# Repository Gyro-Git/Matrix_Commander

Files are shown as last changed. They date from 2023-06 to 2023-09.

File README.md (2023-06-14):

# Matrix Commander

Matrix Commander is an open-source project dedicated to developing a customizable, 3D-printed wireless remote. This project is built around the Arduino line of microcontrollers.
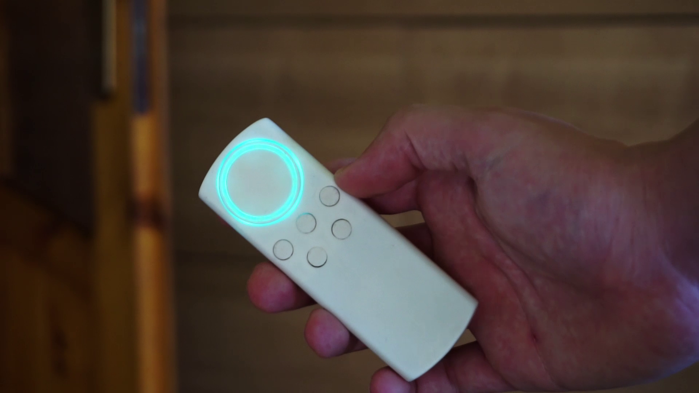
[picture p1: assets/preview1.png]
Matrix Commander

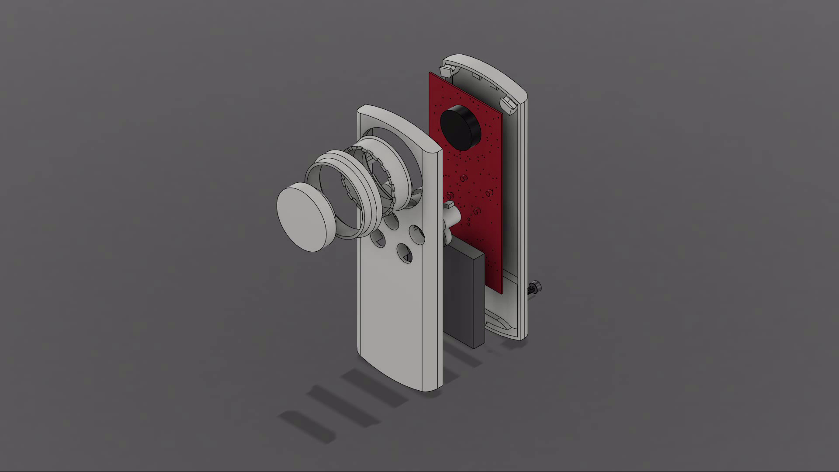
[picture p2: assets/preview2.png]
Matrix Commander render


## About

This project brings together several facets of technology, integrating hardware programming, 3D printing, and wireless connectivity. The end result is a functional human interface device(HID) that can serve as a keyboard or any other HID, making it compatible with any device that supports a regular keyboard.

For detailed instructions on the construction and implementation of Matrix Commander, refer to our comprehensive guide:

**[The Ultimate Wireless Keyboard Mark 2](https://www.instructables.com/The-Ultimate-Wireless-Keyboard-Mark-2/)**

## Key Features

- Arduino programming - providing flexibility for customization
- 3D printed design - allowing personalization
- Functions as a human interface device

## Contributing

Contributions are welcome and appreciated. Feel free to fork the project, make modifications, and submit a Pull Request.

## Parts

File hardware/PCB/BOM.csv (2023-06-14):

Qty | Value | Device | Package | Parts | Description
1 |  | USB_C16PIN | USB-C-16P | J1 | USB Type C 16Pin Connector
1 | 0.4R | R-EU_R0805 | R0805 | R17 | RESISTOR, European symbol
2 | 100nF | C-EUC0603 | C0603 | C3, C6 | CAPACITOR, European symbol
9 | 10K | R-EU_R0603 | R0603 | R3, R5, R7, R8, R9, R10, R11, R12, R27 | RESISTOR, European symbol
2 | 10k | R-EU_R0603 | R0603 | R14, R23 | RESISTOR, European symbol
2 | 10uF | C-EUC0805 | C0805 | C1, C2 | CAPACITOR, European symbol
4 | 10R | R-EU_R0603 | R0603 | R2, R4, R6, R26 | RESISTOR, European symbol
1 | 16Mhz | XTAL-4-3225 | NX3225 | Q2 | Classic 4-pin 3.2 x 2.5mm crystal
4 | 1k | R-EU_R0603 | R0603 | R16, R18, R19, R20 | RESISTOR, European symbol
2 | 1nF | C-EUC0603 | C0603 | C13, C14 | CAPACITOR, European symbol
6 | 1uF | C-EUC0603 | C0603 | C4, C5, C7, C10, C11, C12 | CAPACITOR, European symbol
2 | 22R | R-EU_R0603 | R0603 | R24, R25 | RESISTOR, European symbol
2 | 22pf | C-EUC0603 | C0603 | C8, C9 | CAPACITOR, European symbol
2 | 22R | R-EU_R0603 | R0603 | R29, R30 | RESISTOR, European symbol
1 | 2k7 | R-EU_R0603 | R0603 | R1 | RESISTOR, European symbol
1 | 32U4 | ATMEGA32U4TQFP-44 | TQFP44 | U2 | Atmel MCU, 32KByte
1 | 39R | R-EU_R0603 | R0603 | R28 | RESISTOR, European symbol
2 | 5K1 | R-EU_R0603 | R0603 | R21, R22 | RESISTOR, European symbol
2 | 5M | R-EU_R0603 | R0603 | R13, R15 | RESISTOR, European symbol
2 | AP7313 | AP7313_LINEAR_PWR_REG | SOT23R | IC2, IC3 | 3.3V Voltage Reference 50ppm/°C, SOT23, 3-Terminal
1 | ATMEGA328P_TQFP | ATMEGA328P_TQFP | TQFP32-08 | U1 | Popular 328P in QFP
1 | JST | JST_PH2.0_BAT_CON | JST_PH_2.0_2PIN_CONNECTOR | CON1
8 | LL4148 | DSOD323 | SOD323 | D1, D2, D3, D4, D5, D6, D7, D8 | DIODE
2 | NRF24 | NRF24 | NRF24L01_SMT | U$1, U$9 | SMD version of NRF24L01 wireless transceiver module. Made by Gyro: https://www.youtube.com/c/gyro1
4 | NX7002AK | MOSFET-NREFLOW | SOT23 | Q1, Q3, Q4, Q5 | N-Channel Mosfet
2 | OSHW-LOGOS | OSHW-LOGOS | OSHW-LOGO-S | LOGO1, LOGO2 | Open-Source Hardware (OSHW) Logo
6 | RGB_LED | RGB_LED | 1.6X1.6_RGB_LED | LED1, LED3, LED5, LED7, LED9, LED13
1 | SIQ-ROTARY_ENCODER | SIQ-ROTARY_ENCODER | SIQ-02FVS3 | SW1
5 | TAC_SWITCHSMD | TAC_SWITCHSMD | TACTILE-SWITCH-SMD | S1, S2, S3, S4, S5 | Momentary Switch
1 | TP4056 | TP4056 | SOP-8 | IC1
1 | USB-A | USB-A | USB-A-SMT-MALE | U$8

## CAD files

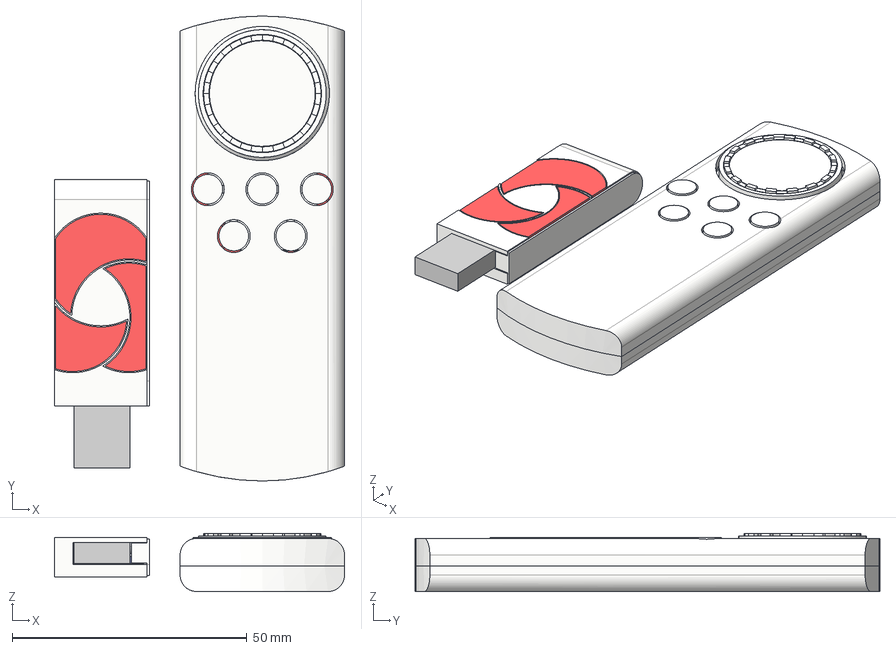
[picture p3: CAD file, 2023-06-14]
hardware/3D_models/Matrix_Commander.step
61.7 x 99.0 x 12.3 mm
NRF24
ATMEGA328P_TQFP
TP4056
TAC_SWITCHSMD x 5
RGB_LED x 11
22R x 21
NX7002AK x 3
AP7313
LL4148 x 8
OSHW-LOGOS
10uF x 2
0.4R
1uF x 3
PAD_POGO_PIN x 8
Skrutka
zavit
Buttons
Bottom
Top
li-po 500mah
mid
out
ring
receiver

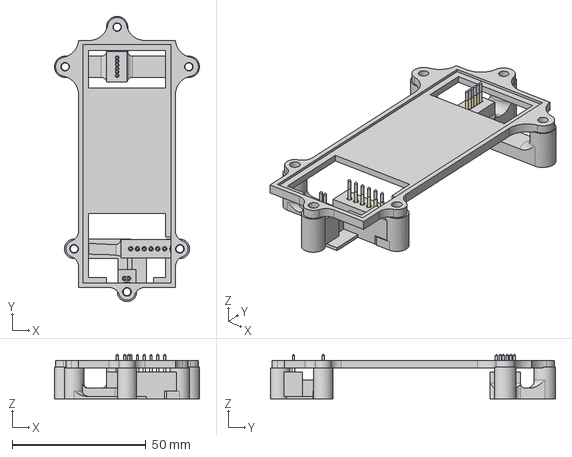
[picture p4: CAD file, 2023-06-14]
hardware/3D_models/programing_jig.step
54.3 x 106.8 x 16.8 mm
Head x 14

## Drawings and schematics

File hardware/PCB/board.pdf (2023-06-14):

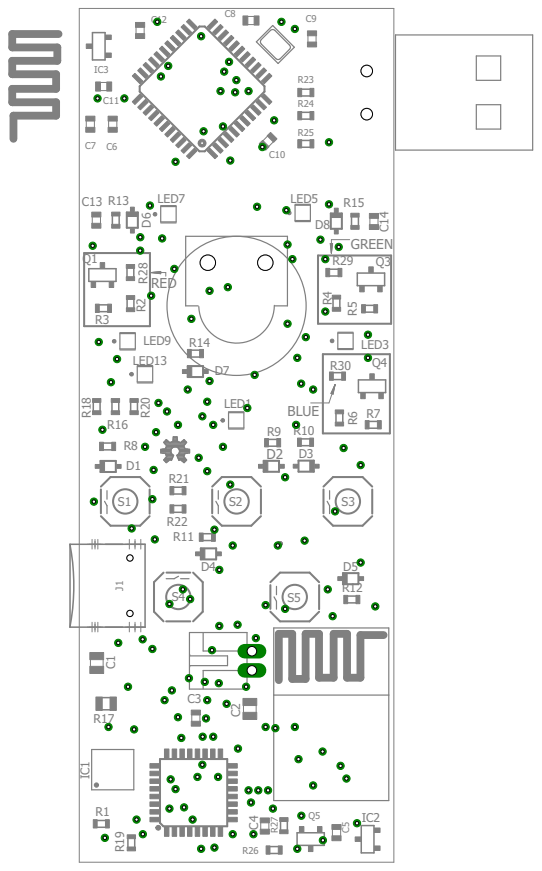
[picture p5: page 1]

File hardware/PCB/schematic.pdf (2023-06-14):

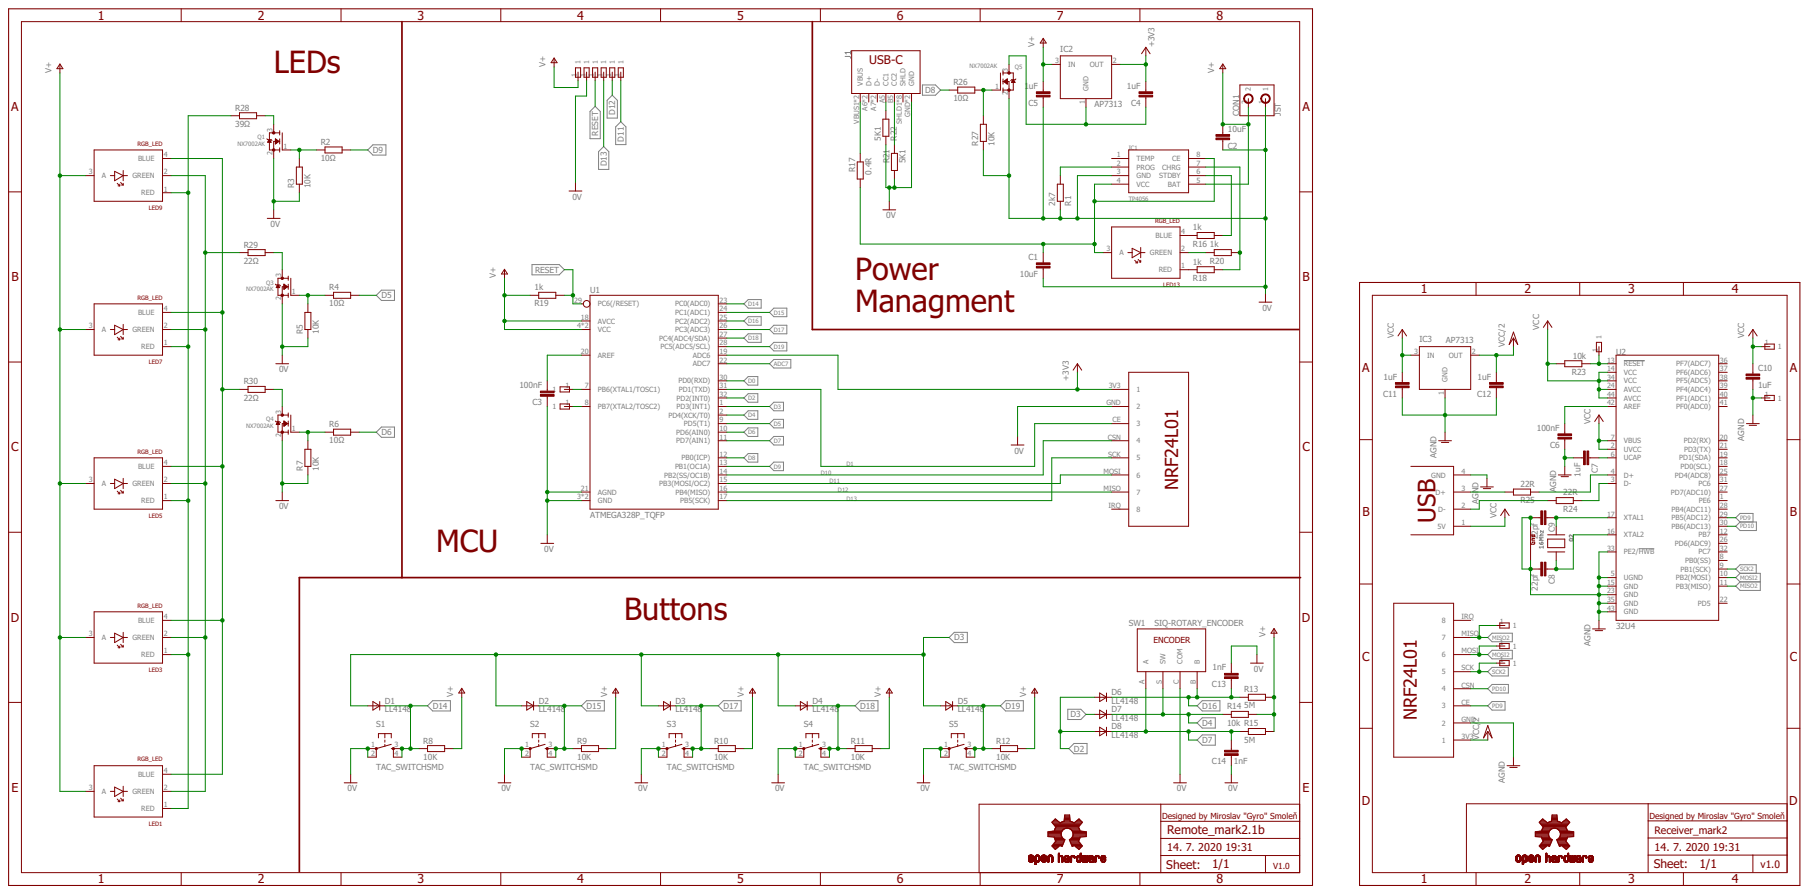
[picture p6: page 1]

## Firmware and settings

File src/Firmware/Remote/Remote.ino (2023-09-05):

#include <SPI.h>
#include <RF24.h>
#include <Bounce2.h>
#include <EEPROM.h>

const int redPin = 9; //pin for red LED
const int greenPin = 5;
const int bluePin = 6;
const int lowVPin = 8;
const int batPin = 20; //pin 20 is A6

const int rotA = 7; //Rotary encoder pin A
const int rotB = 16;
const int modeButton = 4;
const int A = 14; //button A
const int B = 15;
const int X = 17;
const int Y = 18;
const int Z = 19;

unsigned int standByTime = 3000; //in ms
unsigned int listenTime = 1000; // in ms
volatile bool input = false;
long startTime;
int message = 0;
int Alast;
int Blast;
static uint16_t state = 0, rotCount = 0;

uint8_t Red = 100;
uint8_t Green = 100;
uint8_t Blue = 50;
float Bright = 0.5;

//variables for modes
byte modes[32][3];
byte numberOfModes;
byte currentMode;
bool Awaken = false;
//temporary configuration
byte tempModes[32][3];

byte lowBattLight = 255;
unsigned long battTime;
byte battLoops = 0;
bool battAnim = true;
bool emptyBatt = false;
float fadeInAmount = 1.0;
unsigned long fadeInTime;
bool fadeInAnim = true;
float fadeOutAmount = 1.0;
unsigned long fadeOutTime;
bool fadeOutAnim = true;
float stepFadeOut = 0.04;
float fadeOutDelay = 5.0;

unsigned long buttonTime;
unsigned long repeatTime;

struct configuration {
  unsigned long mode[16];
} myconfig;

//radio configuration
RF24 radio(1, 10);
byte addresses[][6] = {"1Node", "2Node"};

Bounce bouncer1 = Bounce();
Bounce bouncer2 = Bounce();
Bounce bouncerA = Bounce();
Bounce bouncerB = Bounce();
Bounce bouncerX = Bounce();
Bounce bouncerY = Bounce();
Bounce bouncerZ = Bounce();
Bounce bouncerM = Bounce();



void loop() {
  if (input) {        //only occurs during isr method which is interrupt
    emptyBatt = false;
    startTime = millis();
    fadeInAnim = true;
    fadeInAmount = 0.0;
    fadeInTime = millis();
    fadeOutAmount = 1.0;
    repeatTime = millis();
    buttonTime = millis();
    if (isBatteryEmpty()) {
      emptyBatt = true;
      battAnim = true;
      fadeInAnim = false;
      turnOffLight();
      battLoops = 0;
      lowBattLight = 255;
      battTime = millis();
    }
    while (millis() - startTime < standByTime) {
      checkButtons();
    }
  }
  turnOffLight();
  EEPROM.update(210, currentMode);
  Awaken = false;
  checkForUpdate();
  if (!Awaken) {
    enterSleep();       //puts arduino to sleep to save power
  }
  //turnOnLight(1.0);
}


void checkButtons() {       //Scans which button is pressed and sends message
  if (emptyBatt && battAnim) {
    analogWrite(redPin, lowBattLight * Bright);
    if (millis() - battTime > 6) {
      lowBattLight -= 4;
      if (lowBattLight <= 4) {
        lowBattLight = 255;
        battLoops++;
      }
      if (battLoops >= 2) {
        battAnim = false;
        fadeInAnim = true;
      }
      battTime = millis();
    }
  }

  if (fadeInAnim) {
    if (millis() - fadeInTime > 5) {
      turnOnLight(fadeInAmount);
      fadeInAmount += 0.04;
      fadeInTime = millis();
    }
    if (fadeInAmount >= 1.0) {
      fadeInAnim = false;
      turnOnLight(1.0);
    }
  }


  if (millis() - startTime > standByTime - (1 / stepFadeOut)*fadeOutDelay) {
    if (millis() - fadeOutTime > fadeOutDelay) {
      turnOnLight(fadeOutAmount);
      fadeOutAmount -= stepFadeOut;
      fadeOutTime = millis();
    }
  }

  message = 0;
  bouncer1.update();
  bouncer2.update();
  bouncerA.update();
  bouncerB.update();
  bouncerX.update();
  bouncerY.update();
  bouncerZ.update();
  bouncerM.update();
  unsigned int longPressDelay = 400;
  unsigned int repeatPressDelay = 33;

  if (bouncerA.fell()) {
    message = 1;
    startTime = millis();
    sendButton(message);
  }
  if (!bouncerA.read()) {
    if (!bouncerA.rose()) {
      if (millis() - buttonTime > longPressDelay) {
        if (millis() - repeatTime > repeatPressDelay) {
          sendButton(1);
          startTime = millis();
          repeatTime = millis();
        }
      }
    }
    input = false;
    return;
  }

  if (bouncerB.fell()) {
    message = 2;
    startTime = millis();
    sendButton(message);
  }
  if (!bouncerB.read()) {
    if (!bouncerB.rose()) {
      if (millis() - buttonTime > longPressDelay) {
        if (millis() - repeatTime > repeatPressDelay) {
          sendButton(2);
          startTime = millis();
          repeatTime = millis();
        }
      }
    }
    input = false;
    return;
  }

  if (bouncerX.fell()) {
    message = 3;
    startTime = millis();
    sendButton(message);
  }
  if (!bouncerX.read()) {
    if (!bouncerX.rose()) {
      if (millis() - buttonTime > longPressDelay) {
        if (millis() - repeatTime > repeatPressDelay) {
          sendButton(3);
          startTime = millis();
          repeatTime = millis();
        }
      }
    }
    input = false;
    return;
  }

  if (bouncerY.fell()) {
    message = 4;
    startTime = millis();
    sendButton(message);
  }
  if (!bouncerY.read()) {
    if (!bouncerY.rose()) {
      if (millis() - buttonTime > longPressDelay) {
        if (millis() - repeatTime > repeatPressDelay) {
          sendButton(4);
          startTime = millis();
          repeatTime = millis();
        }
      }
    }
    input = false;
    return;
  }

  if (bouncerZ.fell()) {
    message = 5;
    startTime = millis();
    sendButton(message);
  }
  if (!bouncerZ.read()) {
    if (!bouncerZ.rose()) {
      if (millis() - buttonTime > longPressDelay) {
        if (millis() - repeatTime > repeatPressDelay) {
          sendButton(5);
          startTime = millis();
          repeatTime = millis();
        }
      }
    }
    input = false;
    return;
  }

  if (bouncerM.fell()) {
    changeMode();
    startTime = millis();
  }


  if (bouncer1.fell()) {
    if (bouncer2.read()) {
      message = 6;
    } else {
      message = 7;
    }
  }

  if (message != 0) {
    startTime = millis();
    sendButton(message);
  }
  input = false;                        //prevents from looping
  buttonTime = millis();
}

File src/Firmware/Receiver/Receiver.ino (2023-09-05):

#include "Arduino.h"
#include <SPI.h>
#include <RF24.h>
#include "HID-Project.h"
#include <EEPROM.h>

// This is just the way the RF24 library works:
// Hardware configuration: Set up nRF24L01 radio on SPI bus (pins 10, 11, 12, 13) plus pins 7 & 8
RF24 radio(9, 10);

byte addresses[][6] = {"1Node", "2Node"};
byte currentConf[128];

void setup()
{
  Keyboard.begin();
  Consumer.begin();
  if (!radio.begin()) //if radio can't be found turn on all LEDs and do nothing.
  {
    while (1); // Radio can't be initialized. Reset necessary
    Keyboard.print("Dongle is broken");
  }
  radio.setPALevel(RF24_PA_MAX);  //adjustable power level
  radio.setDataRate(RF24_250KBPS); //slowest speed for higher range
  radio.setChannel(124);
  radio.setPayloadSize(1);

  radio.openWritingPipe(getPipe(1));
  radio.openReadingPipe(1, getPipe(0));
  pinMode(8, OUTPUT);
  radio.startListening();
  //Serial.begin(115200);
  loadConfig();
}

void loop() {
  radio.startListening();
  // This is what we receive from the other device (the transmitter)
  byte data;
  byte confirmation = 0;

  // Is there any data for us to get?
  if ( radio.available()) {

    // Go and read the data and put it into that variable
    while (radio.available()) {
      radio.read( &data, sizeof(byte));

      if (data == 8) {    //check config
        bool isMatch = checkConfig();
        if (isMatch) {}//Serial.println("Config matches");
        else {
          //Serial.println("Config doesn't match");
          updateRemote();
        }
      }
      else {   //press button as HID after confirmation message
        byte confirmation = 0;
        unsigned long startTime = millis();
        while (millis() - startTime < 10) {
          if ( radio.available()) {
            while (radio.available()) {
              radio.read( &confirmation, sizeof(byte));
              //Serial.println(confirmation);
            }
            if (confirmation == 249) HIDaction(data);
          }
        }
      }
      data = 0;

    }
  }
}

bool checkConfig() {
  //Serial.println("checking configuration");
  //Keyboard.print("checking configuration");
  unsigned long startedWaitingAt = millis();
  int count = 0;
  bool isConfRight = true;
  byte data;
  byte Tx;
  while (1) {
    if ( radio.available()) {
      while (radio.available()) {
        radio.read( &data, sizeof(byte));
        if (count == 128 && isConfRight && data == 16) break;
        if (data != currentConf[count]) isConfRight = false;
        //Serial.print(data);
        //Serial.print(" | ");
        //Serial.println(currentConf[count]);
        count++;
        data = 0;
      }
    }
    if (millis() - startedWaitingAt > 200) {
      //Keyboard.print(" communication interrupted");
      return true;
    }
    if (count >= 129) break;
  }
  if (isConfRight) {
    radio.stopListening();
    Tx = 16;
    if (!radio.write( &Tx, sizeof(byte)))
    {
      //Serial.println("Couldn't send confirmation");
    }
  }
  //Keyboard.print(" cofing is ok");
  return isConfRight;
}

bool updateRemote() {
  //Serial.println("updating remote");
  //Keyboard.print("updating remote");
  radio.stopListening();
  byte Tx;
  for (int i = 0; i < sizeof(currentConf); i++) {
    Tx = currentConf[i];
    if (!radio.write( &Tx, sizeof(byte)))
    {
      //Serial.println("failed updating");
    }
  }
}

uint64_t getPipe(byte index) {
  uint64_t out;
  if (index == 1) index = 5;
  else index = 0;
  out += EEPROM.read(200 + index);
  out = out << 8;
  out += EEPROM.read(201 + index);
  out = out << 8;
  out += EEPROM.read(202 + index);
  out = out << 8;
  out += EEPROM.read(203 + index);
  out = out << 8;
  out += EEPROM.read(204 + index);
  return out;
}
